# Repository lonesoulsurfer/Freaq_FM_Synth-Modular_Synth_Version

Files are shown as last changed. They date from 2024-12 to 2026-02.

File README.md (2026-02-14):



# Freaq_FM_Synth-Modular_Synth_Version

UPDATE: I have updated the original Freq Code so it now works on the current Mozzi Library.  You can find this updated code in the 'Freaq_Updated_Code' file.  I don't believe that there is any difference in sound quality and it is exactkly the same as the original which I have also included.  Both files can be found in the 'Frea_IDE_Code' folder

 The awesome Freaq FM Synth by MeeBleeps - designed for Eurorack Synths

Youtube Vid - https://www.youtube.com/watch?v=fAgmykZD0DI&source_ve_path=Mjg2NjY

First and foremost - I need to do a huge shoutout to MeeBleeps who designed this amazing synth! - https://github.com/Meebleeps/MeeBleeps-Freaq-FM-Synth

My contribution has been the design of a PCB and front panel to suit a Eurorack to suit modular synth builds.  It can be run from 12V power supply via a power connector used on on Euroracks or a 9V power supply via a JST connector.

It also can be used as a standalone synth and hand on heart, holds up to most mini synths you can buy.

The main goal with building this module is to create my own 'simple to build' modular synth. I wanted to keep everything as easy as possble with each module built with the following aims:

 - Can be powered by 9V (and 12V)
 - Easy to build with minimum components
 - Use Arduino to keep it simple (plus it helps to keep the components down and everything in tune)
 - Can fit into any modular synth Eurorck (include the ability to power the module via normal module power sources)
 - Has to sound great!

I've created a step by step guide on my Instructables page which you can find below.  This goes through how to upload the sketch using the correct version of Mozzie (1.1.2).  
https://www.instructables.com/Freaq-FM-Synth/

The Freaq FM Synth features dual independent 2-operator FM voices paired with a 2-track generative sequencer. You can stack the voices so they are in unison or have them in different polymeric step-counts. This allows you to have one voice play bass and the other lead.

This is one funky little machine! There are a tonne of controls and waveforms along with attack/delay envelope and LFO per voice.

Full instructions can be found in the Github repository



NOTE - the default start-up on the Freaq has mutation and density very low which means you might only hear a couple bleeps and boops and not much else.  To get the synth going just turn the mutation knob fully left then fully right.  Then hold down the FUNC button and do the same thing again.  This will reset the mutation & density and you'll be good to go.

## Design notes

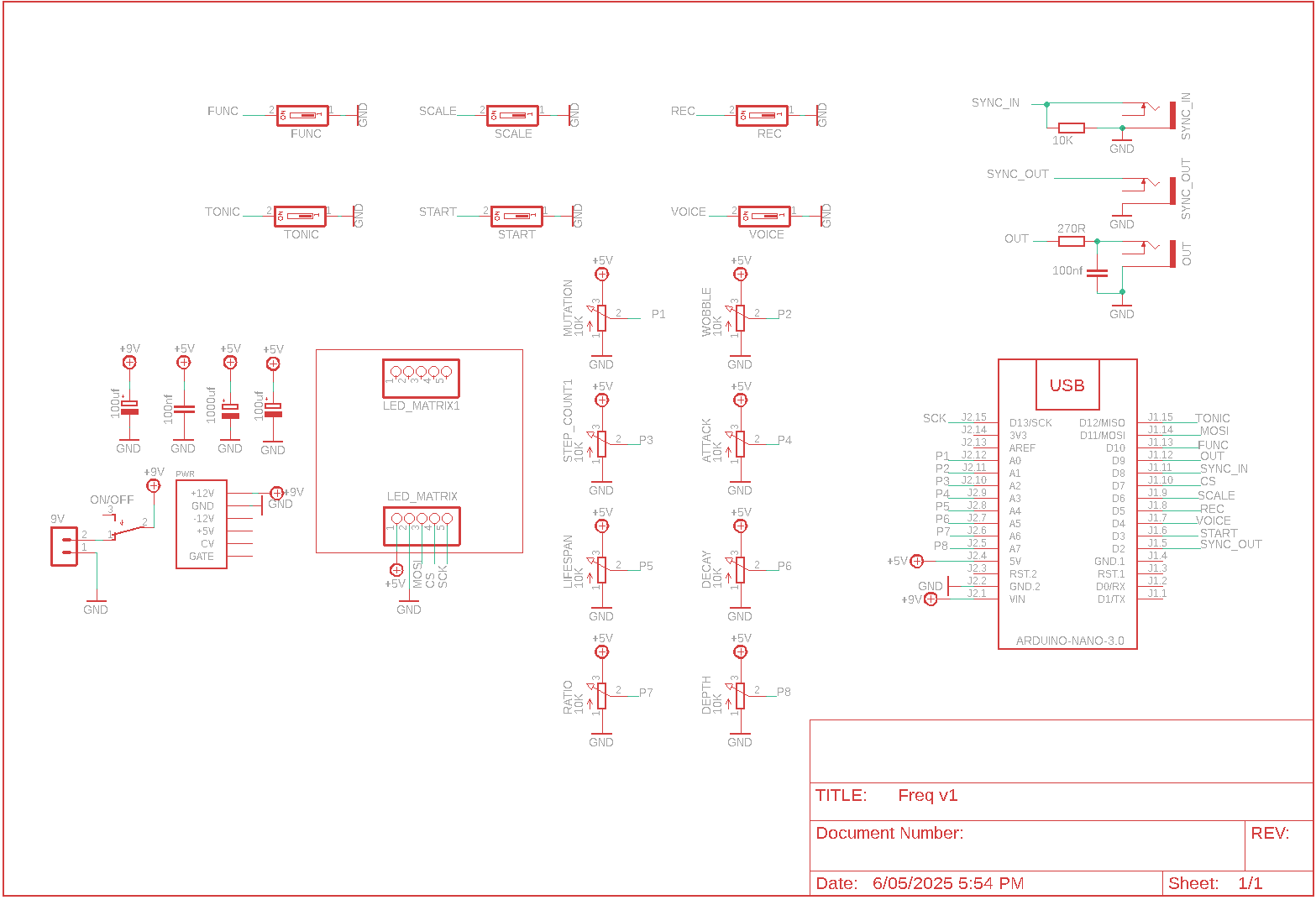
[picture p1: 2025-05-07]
Schematic.png

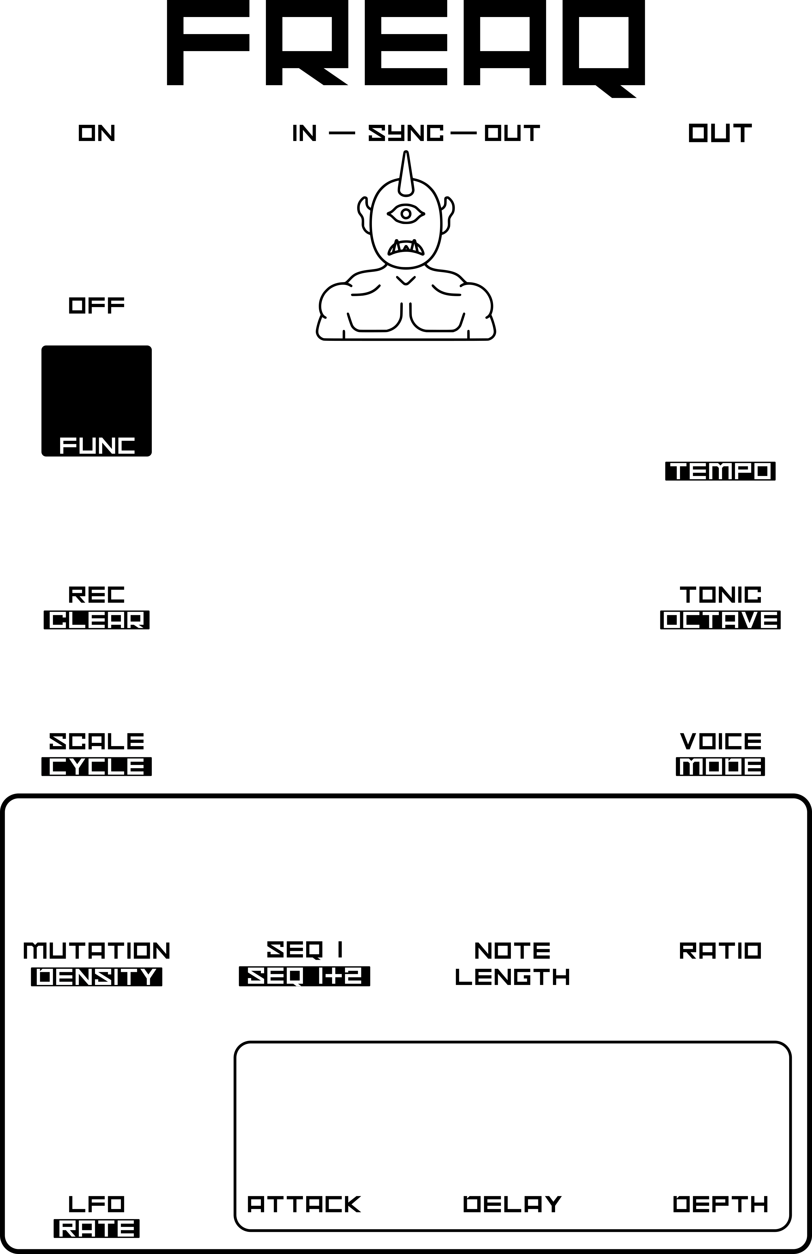
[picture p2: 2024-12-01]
Front Panel.png

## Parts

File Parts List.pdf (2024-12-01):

Part Type Value Qty | Image | Link | Notes
Capacitor Polypropylene 104J 100nf 2 | | Link (https://vi.aliexpress.com/w/wholesale-capacitor-100nf.html?spm=a2g0o.productlist.search.0)
100uf 2 Capacitor Polarized esr 1000uf 1 | | Link (https://vi.aliexpress.com/w/wholesale-capacitor-100uf-.html?spm=a2g0o.productlist.search.0) Link (https://vi.aliexpress.com/w/wholesale-capacitor-1000uf-esr.html?spm=a2g0o.productlist.search.0) | I like to use high frequency, low noise capacitors

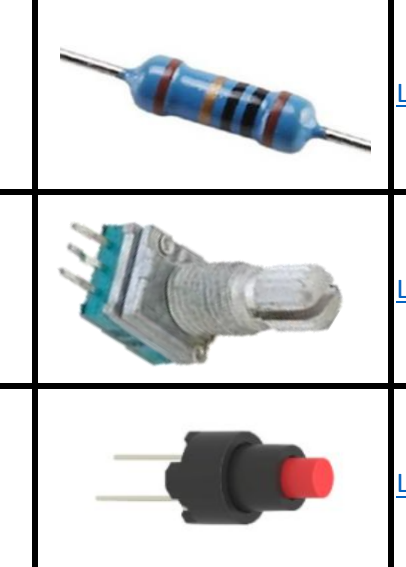
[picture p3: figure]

10K 1 Resistors Metal Film 1% 270R 1 | | Link (https://vi.aliexpress.com/w/wholesale-resistor-metal-film.html?spm=a2g0o.productlist.search.0)
Potentiometers 9mm Vertical 10K 6 | | Link (https://www.aliexpress.com/w/wholesale-9mm-vertical-potentiometer.html) | Use the metal sharft type. You can use the nut on these to help secure the front panel to the PCB
Momentary (PN SKRCADD010) 8 Switch On/Off Toggle Switch Through 1 Hole version | | Link (https://www.aliexpress.com/w/wholesale-SKRCADD010.html?spm=a2g0o.productlist.search.0) Link (https://vi.aliexpress.com/item/1005001510219617.html) | Make sure that the pins on the switch are Stich pins and are able to go through the holes in the PBC
LED Dot Matrix TZT MAX7219 1 | | Link | Here is an exact link to the one that I used (https://vi.aliexpress.com/item/1005004118366858.html)
Female Header Pin Socket 15 Pin 2 | | Link (https://vi.aliexpress.com/w/wholesale-Single-Row-Female-2.54MM-Spacing-Pin.html) | These are used to hold the Arduino into place. You could solder the Arduino onto the PCB but be careful of shorts that may happen against the components on the other side
Arduino Nano 3 1 | | Link (https://vi.aliexpress.com/w/wholesale-arduino-nano.html?spm=a2g0o.detail.search.0)

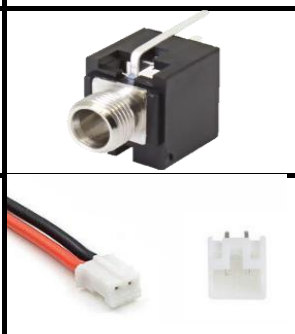
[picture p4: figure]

Audio Socket 3.5mm (PN - PJ-301M) 3 | | Link (https://vi.aliexpress.com/item/1005005352992401.html?scm_id=1007.40050.354490.0&scm-url=1007.40050.354490.0)
Mini JST Connector and wire 2 Pin 1 | | Link (https://vi.aliexpress.com/item/1005005939956886.html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) | This is used to either power the PCB or to test it. If you are going with the 9v battery then you could leave this

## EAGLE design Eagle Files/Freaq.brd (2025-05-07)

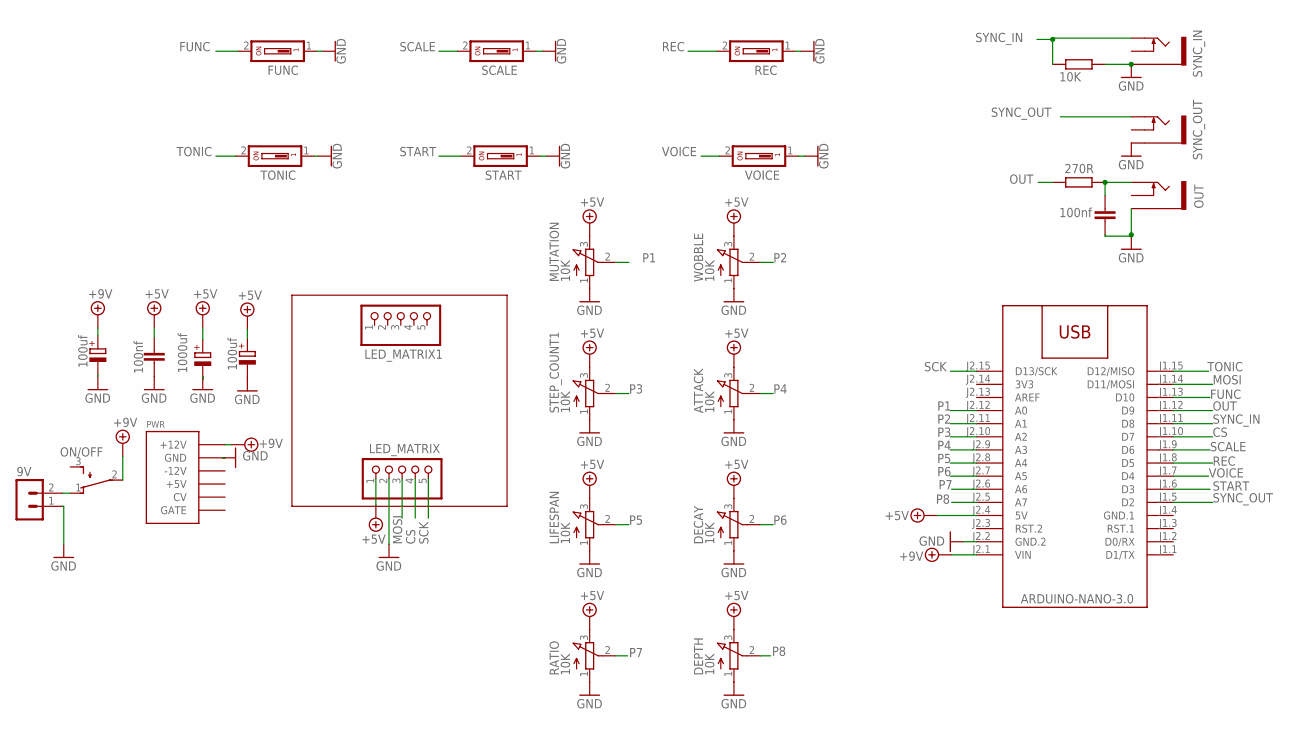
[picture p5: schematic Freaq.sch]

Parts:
9V: B2B-PH-K-S
ATTACK: 10K; EVUFXL
C1, C4: 100nf; C050-024X044
C2, C3: 100uf; E2-5
C5: 1000uf; E2,5-6E
DECAY: 10K; EVUFXL
DEPTH: 10K; EVUFXL
FUNC: DS01; DS-01
LED_MATRIX, LED_MATRIX1: PINHD-1X5; 1X05
LIFESPAN: 10K; EVUFXL
M1: ARDUINO-NANO-3.0
MUTATION: 10K; EVUFXL
ON/OFF: TL32PO; TL3XPO
OUT: THONKICONNNEW; WQP-PJ301M-12_JACK
PWR: POWER; POWER_16
R7: 10K; 0207/10
R8: 270R; 0207/10
RATIO: 10K; EVUFXL
REC: DS01; DS-01
SCALE: DS01; DS-01
START: DS01; DS-01
STEP_COUNT1: 10K; EVUFXL
SYNC_IN: THONKICONNNEW; WQP-PJ301M-12_JACK
SYNC_OUT: THONKICONNNEW; WQP-PJ301M-12_JACK
TONIC: DS01; DS-01
VOICE: DS01; DS-01
WOBBLE: 10K; EVUFXL

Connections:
3V3: M1.J2.14 (3V3)
+5V: ATTACK.3 (E), C1.1, C2.+, C5.+, DECAY.3 (E), DEPTH.3 (E), LED_MATRIX.1, LIFESPAN.3 (E), M1.J2.4 (5V), MUTATION.3 (E), RATIO.3 (E), STEP_COUNT1.3 (E), WOBBLE.3 (E)
+9V: C3.+, M1.J2.1 (VIN), ON/OFF.2, PWR.9 (+12V), PWR.10 (+12V)
CS: LED_MATRIX.4, M1.J1.10 (D7)
FUNC: FUNC.2, M1.J1.13 (D10)
GND: 9V.1, ATTACK.1 (A), C1.2, C2.-, C3.-, C4.2, C5.-, DECAY.1 (A), DEPTH.1 (A), FUNC.1, LED_MATRIX.2, LIFESPAN.1 (A), M1.J2.2 (GND.2), MUTATION.1 (A), OUT.P$3_SLEEVE (SLEEVE), PWR.3 (GND), PWR.4 (GND), PWR.5 (GND), PWR.6 (GND), PWR.7 (GND), PWR.8 (GND), R7.2, RATIO.1 (A), REC.1, SCALE.1, START.1, STEP_COUNT1.1 (A), SYNC_IN.P$3_SLEEVE (SLEEVE), SYNC_OUT.P$3_SLEEVE (SLEEVE), TONIC.1, VOICE.1, WOBBLE.1 (A)
GND.1: M1.J1.4 (GND.1)
MOSI: LED_MATRIX.3, M1.J1.14 (D11/MOSI)
unnamed: 9V.2, ON/OFF.1 (O)
unnamed: C4.1, OUT.P$1_TIP (TIP), R8.2
OUT: M1.J1.12 (D9), R8.1
P1: M1.J2.12 (A0), MUTATION.2 (S)
P2: M1.J2.11 (A1), WOBBLE.2 (S)
P3: M1.J2.10 (A2), STEP_COUNT1.2 (S)
P4: ATTACK.2 (S), M1.J2.9 (A3)
P5: LIFESPAN.2 (S), M1.J2.8 (A4)
P6: DECAY.2 (S), M1.J2.7 (A5)
P7: M1.J2.6 (A6), RATIO.2 (S)
P8: DEPTH.2 (S), M1.J2.5 (A7)
REC: M1.J1.8 (D5), REC.2
SCALE: M1.J1.9 (D6), SCALE.2
SCK: LED_MATRIX.5, M1.J2.15 (D13/SCK)
START: M1.J1.6 (D3), START.2
SYNC_IN: M1.J1.11 (D8), R7.1, SYNC_IN.P$1_TIP (TIP)
SYNC_OUT: M1.J1.5 (D2), SYNC_OUT.P$1_TIP (TIP)
TONIC: M1.J1.15 (D12/MISO), TONIC.2
VOICE: M1.J1.7 (D4), VOICE.2

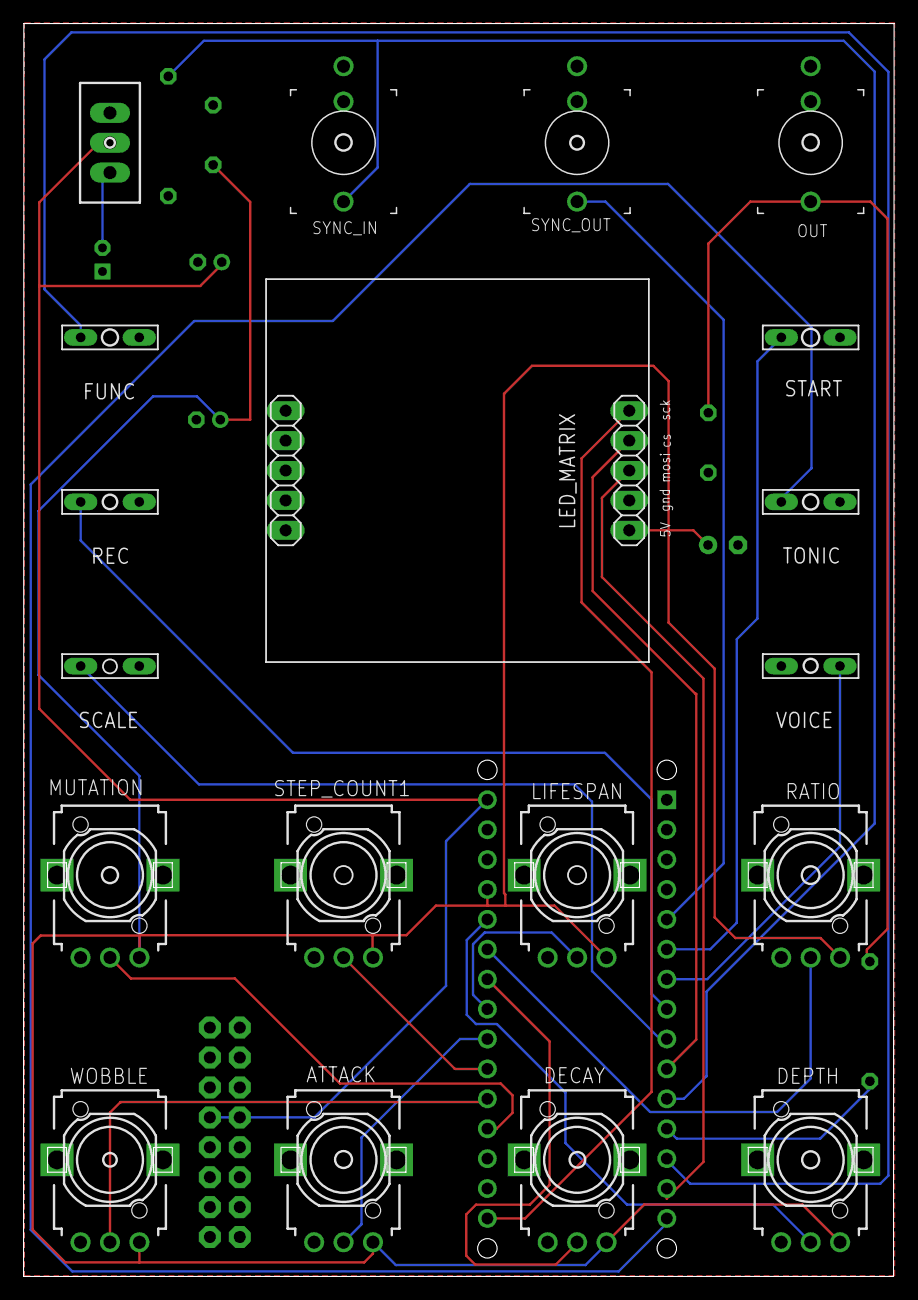
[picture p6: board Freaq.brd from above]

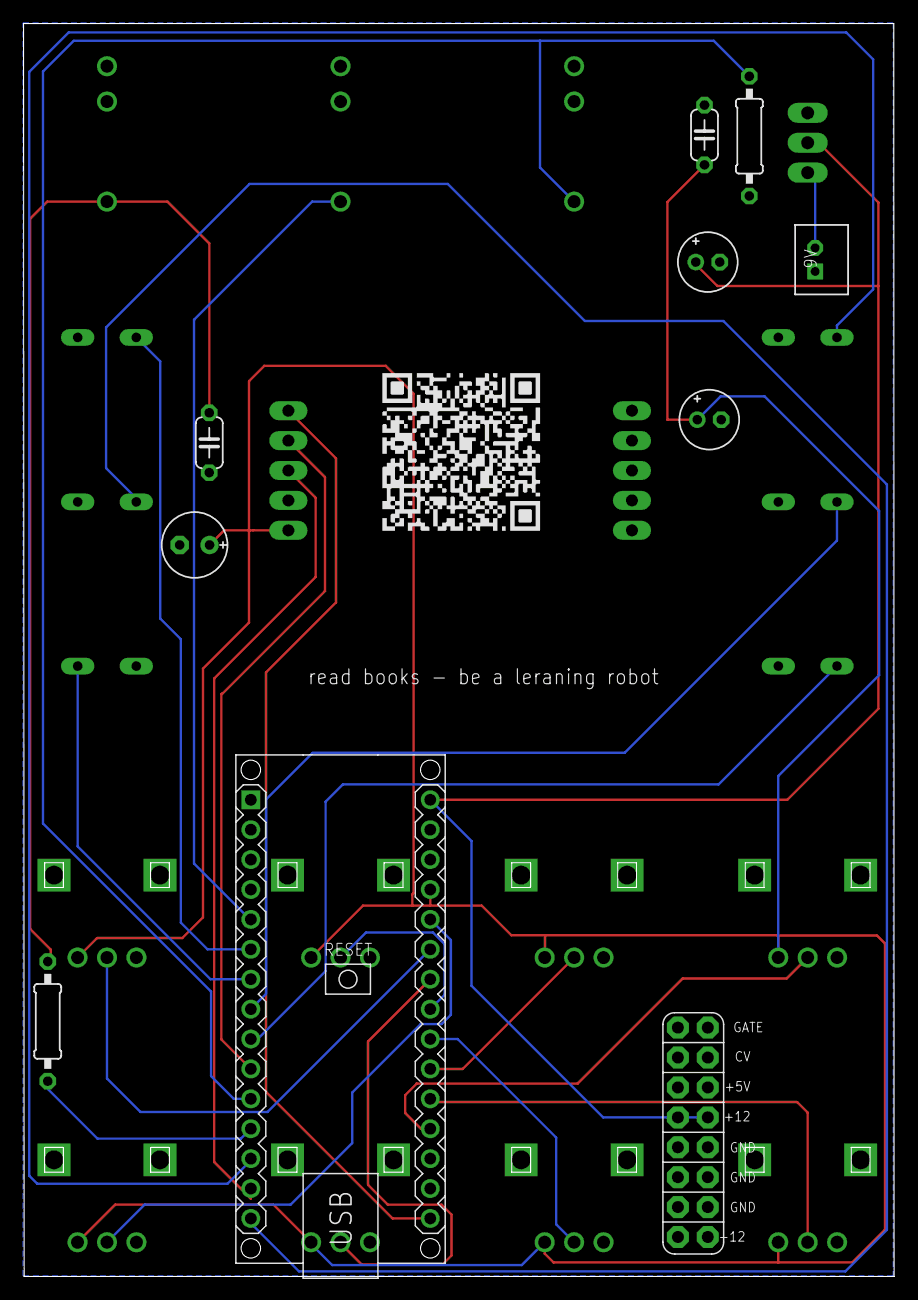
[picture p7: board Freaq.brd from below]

Board: 2 copper layers, 73.9 x 106.4 mm, 30 parts (10 on the bottom side), 25 nets.

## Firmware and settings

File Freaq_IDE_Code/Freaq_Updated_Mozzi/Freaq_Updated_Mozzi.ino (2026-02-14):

/*----------------------------------------------------------------------------------------------------------
 * MutantFMSynth.ino
 * 
 * Main project file for the Mutant FM Synth. 
 * 
 * Instantiates all mutant class objects 
 * Calls the Mozzi audio hook functions
 * manages the user interface
 * 
 * Source Code Repository:  https://github.com/Meebleeps/MeeBleeps-Freaq-FM-Synth
 * Youtube Channel:         https://www.youtube.com/channel/UC4I1ExnOpH_GjNtm7ZdWeWA
 * 
 * (C) 2021-2022 Meebleeps
*-----------------------------------------------------------------------------------------------------------
*/

#include <Arduino.h>

// Mozzi 2.0 Configuration - MUST be before including Mozzi.h
#define MOZZI_CONTROL_RATE 128
#include <Mozzi.h>

#include <mozzi_rand.h>
#include <EventDelay.h>


#include "avSource.h"
#include "avSequencerMultiTrack.h"
#include "avMidi.h"
#include "LedMatrix.h"
#include "mutantBitmaps.h"
#include <avr/pgmspace.h>

#include "MutantFMSynthOptions.h"

// define the pins
#define PIN_SYNC_IN       8
#define PIN_SYNC_OUT      2
#define TIMER_SYNC_PULSE_OUTPUT_MILLIS 15

#define PIN_AUDIO_OUT     9
#define PIN_BUTTON0       4
#define PIN_BUTTON1       5
#define PIN_BUTTON2       6
#define PIN_BUTTON3       3
#define PIN_BUTTON4       10
#define PIN_BUTTON5       12
#define MAX_BUTTON_INPUTS 6

#define SEQUENCER_TRACK_0   0
#define SEQUENCER_TRACK_1   1
#define SEQUENCER_TRACK_0_DISPLAY_ROW_0   4
#define SEQUENCER_TRACK_0_DISPLAY_ROW_1   5
#define SEQUENCER_TRACK_1_DISPLAY_ROW_0   6
#define SEQUENCER_TRACK_1_DISPLAY_ROW_1   7
#define LFO_TRACK_0_DISPLAY_ROW           2
#define LFO_TRACK_1_DISPLAY_ROW           2
#define TRIGGER_DISPLAY_ROW               0
#define TRIGGER_DISPLAY_COL               7
#define CURRENT_VOICE_DISPLAY_ROW         1

#define MAX_ANALOG_INPUTS               8
#define MAX_ANALOG_VALUE                1023

#define ANALOG_INPUT_MOD_AMOUNT         7
#define ANALOG_INPUT_DECAY              4
#define ANALOG_INPUT_MUTATION           0
#define ANALOG_INPUT_LFO                1
#define ANALOG_INPUT_MOD_RATIO          6
#define ANALOG_INPUT_STEPCOUNT          2
#define ANALOG_INPUT_MOD_ENVELOPE1      5
#define ANALOG_INPUT_MOD_ENVELOPE2      3

#define ANALOG_INPUT_MOVEMENT_THRESHOLD 5

// listed in order of left to right.
#define BUTTON_INPUT_FUNC   4
#define BUTTON_INPUT_TONIC  5
#define BUTTON_INPUT_SCALE  2
#define BUTTON_INPUT_START  3
#define BUTTON_INPUT_REC    1
#define BUTTON_INPUT_VOICE  0
#define MAX_OSCILLATOR_MODES 1

#define INTERFACE_MODE_NORMAL 0
#define INTERFACE_MODE_SHIFT  1

#define DISPLAY_SETTING_CHANGE_PERSIST_MILLIS 350
#define DISPLAY_SETTING_INTENSITY 1

#define MOTION_RECORD_NONE  0
#define MOTION_RECORD_REC   1
#define MOTION_RECORD_CLEAR 2

// MOZZI variables
// MOZZI_CONTROL_RATE now defined at top of file (before Mozzi.h include)
// original had at 256 but as CPU got tight had to reduce it
// needs to be at least 128. 64Hz means incoming sync pulses are regularly missed between updates.

// todo:  decrease INTERFACE_UPDATE_DIVIDER  if controls are externally modulated via CV voltage inputs
#define INTERFACE_UPDATE_DIVIDER_ANALOG 5
#define INTERFACE_UPDATE_DIVIDER_DIGITAL 7
#define INTERFACE_UPDATE_DIVIDER_LFO 2
#define INTERFACE_UPDATE_DIVIDER_DISPLAY 32


byte firstTimeStart = true;
byte iTrigger = 1;      
byte iLastTrigger = 0;
byte interfaceMode    = INTERFACE_MODE_NORMAL;
byte controlSynthVoice = 0;
byte motionRecordMode = MOTION_RECORD_NONE;

int iLastAnalogValue[MAX_ANALOG_INPUTS]    = {0,0,0,0,0,0,0,0};
int iCurrentAnalogValue[MAX_ANALOG_INPUTS] = {0,0,0,0,0,0,0,0};

// save space for digital inputs - use a bit rather than a byte per button 
uint8_t bitsLastButton;

// save space for digital inputs - use a bit rather than a byte per button 
uint8_t bitsCurrentButton;

// save space for param lock flags - use a bit rather than a byte per param 
uint8_t bitsLastParamLock;

// time since the last updateAudio()
uint32_t lastUpdateMicros;

// used to divide the calls to updateControl to spread out control reads and save cpu cycles 
uint8_t updateCounter = 0;




// voice 1 instance
MutatingFM          voice0;

// voice 2 instance
MutatingFM          voice1;

// array of pointers to the MutatingFM instances to simplfy the code
MutatingFM*         voices[2];  

// MAX7219 display matrix interface class
LedMatrix           ledDisplay;

// timer to pull sync output low at end of pulse
EventDelay          syncOutputTimer;

// timer to prevent update of the display while a settings icon is being displayed
EventDelay          settingDisplayTimer;

// the sequencer
MutatingSequencerMultiTrack sequencer;





/*----------------------------------------------------------------------------------------------------------
 * setup()
 *----------------------------------------------------------------------------------------------------------
 */
void setup() 
{
  #ifdef ENABLE_MIDI_OUTPUT
  Serial.begin(31250);
  #else
  Serial.begin(115200);
  Serial.print(F("\n\n\n\n\n-----------------------------------------------------------------------\n"));
  Serial.print(F("Freaq - Mozzi-based Mutating FM Synth.   Build "));
  Serial.print  (__DATE__);
  Serial.print  (F(" "));
  Serial.println  (__TIME__);
  #endif

  initialisePins();
  initialiseDisplay();
  initialiseSources();
  initialiseSequencer();
  
  startMozzi(); // Mozzi 2.0: no parameters
}


/*----------------------------------------------------------------------------------------------------------
 * debugPrintMemoryUsage
 * does nothing now.  used while optimising memory usage 
 *----------------------------------------------------------------------------------------------------------
 */
void debugPrintMemoryUsage()
{
/*
  debugWriteValue("sizeof(synthVoice)", sizeof(synthVoice));
  debugWriteValue("sizeof(sequencer)", sizeof(sequencer));
*/  

}


/*----------------------------------------------------------------------------------------------------------
 * initialiseDisplay
 *----------------------------------------------------------------------------------------------------------
 */
void initialiseDisplay()
{
  ledDisplay.initialise();
  ledDisplay.setOrientation(LEDMATRIX_ORIENTATION_0);
  
  settingDisplayTimer.start(0);

  
  // display logo
  for (uint8_t i = 10; i < 100; i += 10)
  {
    ledDisplay.clearScreen();
    delay(i);
    displaySettingIcon(BITMAP_MEEBLEEPS);
    delay(i);
  }
  
  //fade logo to target intensity
  for(int i = 15; i>= DISPLAY_SETTING_INTENSITY; i--)
  {
    ledDisplay.setIntensity(i);

    delay(20);
  }
  
//  ledDisplay.setIntensity(DISPLAY_SETTING_INTENSITY);
//  displaySettingIcon(BITMAP_MEEBLEEPS);

  #ifndef ENABLE_MIDI_OUTPUT
  Serial.println(F("initialiseDisplay() complete"));
  #endif
}




/*----------------------------------------------------------------------------------------------------------
 * initialisePins
 *----------------------------------------------------------------------------------------------------------
 */
void initialisePins()
{
  #ifndef ENABLE_MIDI_OUTPUT
  Serial.println(F("initialisePins()"));
  #endif

  pinMode(PIN_SYNC_IN, INPUT);          // sync is pulled down by external pulldown resistor
  pinMode(PIN_SYNC_OUT, OUTPUT);
  pinMode(PIN_BUTTON0, INPUT_PULLUP);   // all other buttons are pulled up by internal pullup resistor
  pinMode(PIN_BUTTON1, INPUT_PULLUP);
  pinMode(PIN_BUTTON2, INPUT_PULLUP);
  pinMode(PIN_BUTTON3, INPUT_PULLUP);
  pinMode(PIN_BUTTON4, INPUT_PULLUP);
  pinMode(PIN_BUTTON5, INPUT_PULLUP);

  pinMode(A0, INPUT);
  pinMode(A1, INPUT);
  pinMode(A2, INPUT);
  pinMode(A3, INPUT);
  pinMode(A4, INPUT);
  pinMode(A5, INPUT); 
  pinMode(A6, INPUT);
  pinMode(A7, INPUT); 

  // initialise 
  bitsLastButton    = 0;
  bitsCurrentButton = 0;

  for (uint8_t i = 0; i < MAX_ANALOG_INPUTS; i++)
  {
    iLastAnalogValue[i]    = 0;
  }
}



/*----------------------------------------------------------------------------------------------------------
 * initialiseSources
 *----------------------------------------------------------------------------------------------------------
 */
void initialiseSources()
{
  voice0.setOscillator(0);
  voice1.setOscillator(1);

  voices[0] = &voice0;  
  voices[1] = &voice1;  
}



/*----------------------------------------------------------------------------------------------------------
 * initialiseSequencer
 *----------------------------------------------------------------------------------------------------------
 */
void initialiseSequencer()
{
  sequencer.setScale(SCALEMODE_MINOR);
  sequencer.newSequence(16);
  sequencer.setMutationProbability(100);  // Mutation fully on (100%)
  sequencer.setNoteProbability(100);      // Density fully on (100%)
}




/*----------------------------------------------------------------------------------------------------------
 * updateControl
 * called by Mozzi Library on CONTROL_RATE frequency
 * spreads out control logic updates so that we don't bog down the CPU
 *
 * every step - check for sync trigger and update sequencer
 * if this gets delayed, note on/off commands will drift
 *----------------------------------------------------------------------------------------------------------
 */
void updateControl()
{
  uint8_t doDisplayUpdate = false;

  lastUpdateMicros = micros();
  updateCounter++;



  // check for incoming sync trigger and if necessary update output sync
  // do every update to ensure minimum sync jitter 
  updateSyncTrigger();

  // update sequencer returns true if the sequencer has moved to next step
  if (updateSequencer())
  {

    // check to see if sequencer should update the output sync pulse
    if (sequencer.outputSyncPulse())
    {
      outputSyncPulse();
    }

    //update the display once per sequencer step   
    // but do the display update at the end of updateControl so that any latency is introduced after all critical functions are processed

    doDisplayUpdate = true; 
  }
  // check controls once every INTERFACE_UPDATE_DIVIDER steps for efficiency
  // don't update these if the sequencer has updated as that is expensive
  else if(updateCounter % INTERFACE_UPDATE_DIVIDER_ANALOG == 0)
  {
    // now check analog controls
    updateAnalogControls();
  
  }
  // never check both analog and digital controls in the same step to causing buffer underflows
  else if(updateCounter % INTERFACE_UPDATE_DIVIDER_DIGITAL == 0)
  {
    // check button controls first to ensure interface mode is correctly set
    updateButtonControls();

  }
  else if(updateCounter % INTERFACE_UPDATE_DIVIDER_LFO == 0)
  {
    //update display of LFO modulation at higher rate than rest of display
    updateLFOModulationDisplay();
  }
  else 
  {
    doDisplayUpdate = (updateCounter % INTERFACE_UPDATE_DIVIDER_DISPLAY == 0);
  }

  #ifndef ENABLE_MIDI_OUTPUT
  //Serial.print(micros() - lastUpdateMicros);
  //Serial.print(F(","));
  #endif

  // now that all controls are updated, update the source.

  voices[0]->updateControl();
  voices[1]->updateControl();

  #ifndef ENABLE_MIDI_OUTPUT
  /*
  Serial.print(micros() - lastUpdateMicros);
  Serial.print(F(","));
  Serial.print(updateCounter % INTERFACE_UPDATE_DIVIDER_DIGITAL);
  Serial.print(F(","));
  Serial.print(updateCounter % INTERFACE_UPDATE_DIVIDER_ANALOG);
  Serial.print(F(","));
  Serial.print(sequenceUpdated);
  Serial.println();
  */
  #endif

  // do the display update last so that any latency is introduced after the notes are updated
  if (doDisplayUpdate)
  {
    updateDisplay();
  }

}



/*----------------------------------------------------------------------------------------------------------
 * updateLFOModulationDisplay
 * displays the current position of the 2 LFOs using 4 LEDs each
 *----------------------------------------------------------------------------------------------------------
 */
void updateLFOModulationDisplay()
{
  if (!firstTimeStart && settingDisplayTimer.ready())
  {
    // divide LFO value of 0-255 to range 0-3 by right-shift 6 bits, then right-shift 128 by that value to get the correct pixel bitfield
    // originally used floating point maths - very slow.
    ledDisplay.setRowPixels(LFO_TRACK_0_DISPLAY_ROW, (128 >> (voice0.getLFOValue() >> 6)) | (8 >> (voice1.getLFOValue() >> 6)));
    
    ledDisplay.refresh();
  }
}



/*----------------------------------------------------------------------------------------------------------
 * updateSequencer
 * updates sequencer
 * returns true if the sequencer advances a step
 *----------------------------------------------------------------------------------------------------------
 */
int updateSequencer()
{
  byte nextNote[MAX_SEQUENCER_TRACKS];
  uint16_t nextNoteLength;
  
  // if the sequencer is due to make a new step, 
  if (sequencer.update(false))
  {
    nextNoteLength  = sequencer.getNextNoteLength();

    for (uint8_t i=0; i<MAX_SEQUENCER_TRACKS; i++) 
    {
      nextNote[i] = sequencer.getCurrentNote(i);
     
      if (nextNote[i] > 0)
      {
        //todo: find way to extend param locks to channel 2?
        if (i==0)
        {
          getParameterLocks();
        }

        voices[i]->noteOn(nextNote[i], 255, nextNoteLength);

      }
    }
    #ifdef ENABLE_MIDI_OUTPUT
    //midiNoteOn(1,nextNote[0],127);
    if (nextNote[0])
    {
      Serial.write(0x90);
      Serial.write(nextNote[0]-24);
      Serial.write(0x45);
    }
    #else

    #endif


    return true;
  }
  else
  {
    return false;
  }

  
}



/*----------------------------------------------------------------------------------------------------------
 * outputSyncPulse
 * sends a digital signal to the output pin and sets the timer to pull it low after TIMER_SYNC_PULSE_OUTPUT_MILLIS
 *----------------------------------------------------------------------------------------------------------
 */
void outputSyncPulse()
{
  /*
  DEBUG only
  static uint32_t lastSyncOutTimeMicros;
  static uint32_t thisSyncOutTimeMicros;

  thisSyncOutTimeMicros = mozziMicros();
  Serial.print(F("lastSyncOutTimeMicros = "));
  Serial.println(thisSyncOutTimeMicros - lastSyncOutTimeMicros);
  lastSyncOutTimeMicros = thisSyncOutTimeMicros;
  */

  syncOutputTimer.start(TIMER_SYNC_PULSE_OUTPUT_MILLIS);
  digitalWrite(PIN_SYNC_OUT,  HIGH);
}


/*----------------------------------------------------------------------------------------------------------
 * getParameterLocks
 * updates source parameters based on stored modulation sequence
 * parameter locks are only available for first track only.
 *----------------------------------------------------------------------------------------------------------
 */
void getParameterLocks()
{
  uint16_t  thisParamLock;
  uint8_t   thisStep;
  int8_t    synthParamIndex;

  // parameters are recorded on the longest sequence but only applied to track 1 voice
  // this way if track 1 is 5 steps but track 2 is 16 steps, the automation will be 16 steps long
  if (sequencer.getSequenceLength(SEQUENCER_TRACK_1) > sequencer.getSequenceLength(SEQUENCER_TRACK_0))
  {
    thisStep = sequencer.getCurrentStep(SEQUENCER_TRACK_1);
  }
  else
  {
    thisStep = sequencer.getCurrentStep(SEQUENCER_TRACK_0);
  }

  for (uint8_t paramIndex = 0; paramIndex < MAX_PARAMETER_LOCKS; paramIndex++)
  {
    thisParamLock = sequencer.getParameterLock(paramIndex, SEQUENCER_TRACK_0, thisStep);
    
    if (thisParamLock != 0)
    {
      #ifndef ENABLE_MIDI_OUTPUT

      /*
      Serial.print(F("parameter lock for channel "));
      Serial.print(SEQUENCER_TRACK_0);
      Serial.print(F(" parameter "));
      Serial.print(paramIndex);
      Serial.print(F(" value "));
      Serial.println(thisParamLock);
      */
      #endif

      // set the flag for this input - last parameter was a lock
      bitsLastParamLock |= 1 << paramIndex;
    }
    else 
    {
      // if the last step was a parameter lock but this step doesn't have one, set the parameter lock to the current knob position
      if ((bitsLastParamLock >> paramIndex) & 1)
      {
        #ifndef ENABLE_MIDI_OUTPUT

        /*
        Serial.print(F("clearing last parameter lock for channel "));
        Serial.print(SEQUENCER_TRACK_0);
        Serial.print(F(" parameter "));
        Serial.print(paramIndex);
        Serial.print(F(" knob value "));
        Serial.println(iCurrentAnalogValue[getParameterLockControl(paramIndex)]);
        */
        #endif
        thisParamLock = iCurrentAnalogValue[getParameterLockControl(paramIndex)];
      }

      // reset the lock bitflag for this parameter
      bitsLastParamLock &= ~(1 << paramIndex);  

    }
    
    // if there is a parameter lock or we are recovering from a previous step parameter lock 
    if (thisParamLock != 0)
    {
      synthParamIndex = getParameterLockSynthParam(paramIndex);
      
      if (synthParamIndex == -2)
      {
        sequencer.setNextNoteLength(thisParamLock);
      }
      else if (synthParamIndex >= 0)
      {
        voices[SEQUENCER_TRACK_0]->setParam(synthParamIndex, thisParamLock);
      }
    }
    //}
  }

}



/*----------------------------------------------------------------------------------------------------------
 * setParameterLock
 * saves the given parameter value onto a modulation channel
 *----------------------------------------------------------------------------------------------------------
 */
inline void setParameterLock(int8_t paramChannel, uint16_t value)
{
  switch (motionRecordMode)
  {
    // 14/02/22: moved this here as is the most common case, assuming no branch prediction on arduion platforms
    case MOTION_RECORD_NONE:
        // do nothing 
        break;

    case MOTION_RECORD_REC:
        sequencer.setParameterLock(paramChannel, value);
        #ifndef ENABLE_MIDI_OUTPUT
        //Serial.println(F("setParameterLock(0)"));
        #endif
        break;

    case MOTION_RECORD_CLEAR:
        sequencer.clearAllParameterLocks(paramChannel);
        #ifndef ENABLE_MIDI_OUTPUT
        //Serial.println(F("Clear ParameterLock(0)"));
        #endif
        break;

  }
}



/*----------------------------------------------------------------------------------------------------------
 * getParameterLockChannel
 * returns the sequencer modulation channel for a given analog control index 
 * 
 * These are a bit of a kludge - would be better as a lookup table.
 *----------------------------------------------------------------------------------------------------------
 */
inline int8_t getParameterLockChannel(uint8_t analogControlIndex)
{
  switch(analogControlIndex)
  {
    case ANALOG_INPUT_MOD_AMOUNT:    return PARAM_LOCK_CHANNEL_0;       
    case ANALOG_INPUT_DECAY:         return PARAM_LOCK_CHANNEL_1;
    case ANALOG_INPUT_MOD_RATIO:     return PARAM_LOCK_CHANNEL_2;
    case ANALOG_INPUT_MOD_ENVELOPE1: return PARAM_LOCK_CHANNEL_3;
    case ANALOG_INPUT_MOD_ENVELOPE2: return PARAM_LOCK_CHANNEL_4;
    case ANALOG_INPUT_LFO:           return PARAM_LOCK_CHANNEL_5;
    default:  return -1;
  }
}


/*----------------------------------------------------------------------------------------------------------
 * getParameterLockControl
 * returns the analog control index for a given sequencer modulation channel 
 *----------------------------------------------------------------------------------------------------------
 */
inline int8_t getParameterLockControl(uint8_t paramChannelIndex)
{
  switch(paramChannelIndex)
  {
    case PARAM_LOCK_CHANNEL_0: return ANALOG_INPUT_MOD_AMOUNT;
    case PARAM_LOCK_CHANNEL_1: return ANALOG_INPUT_DECAY;
    case PARAM_LOCK_CHANNEL_2: return ANALOG_INPUT_MOD_RATIO;
    case PARAM_LOCK_CHANNEL_3: return ANALOG_INPUT_MOD_ENVELOPE1;
    case PARAM_LOCK_CHANNEL_4: return ANALOG_INPUT_MOD_ENVELOPE2;
    case PARAM_LOCK_CHANNEL_5: return ANALOG_INPUT_LFO;
    default:  return -1;
  }
}


/*----------------------------------------------------------------------------------------------------------
 * getParameterLockSynthParam
 * returns the sytnh parameter for a given sequencer modulation channel 
 *----------------------------------------------------------------------------------------------------------
 */
inline int8_t getParameterLockSynthParam(uint8_t paramChannelIndex)
{
  switch(paramChannelIndex)
  {
    case PARAM_LOCK_CHANNEL_0: return SYNTH_PARAMETER_MOD_AMOUNT;
    case PARAM_LOCK_CHANNEL_1: return SYNTH_PARAMETER_NOTE_DECAY;
    case PARAM_LOCK_CHANNEL_2: return SYNTH_PARAMETER_MOD_RATIO;
    case PARAM_LOCK_CHANNEL_3: return SYNTH_PARAMETER_ENVELOPE_DECAY;
    case PARAM_LOCK_CHANNEL_4: return SYNTH_PARAMETER_ENVELOPE_ATTACK;
    case PARAM_LOCK_CHANNEL_5: return SYNTH_PARAMETER_MOD_AMOUNT_LFODEPTH;
    default:  return SYNTH_PARAMETER_UNKNOWN;
  }
}






/*----------------------------------------------------------------------------------------------------------
 * updateSyncTrigger
 * check for incoming sync trigger and update sequencer
 * also check to see if output sync trigger needs to be pulled low
 *----------------------------------------------------------------------------------------------------------
 */
void updateSyncTrigger()
{
  iTrigger = digitalRead(PIN_SYNC_IN);   // read the sync pin
  if (iTrigger != iLastTrigger)
  {
    digitalWrite(PIN_SYNC_OUT, iTrigger);
    
    //trigger note on or off
    if (iTrigger == HIGH)
    {
      #ifndef ENABLE_MIDI_OUTPUT
      //Serial.println("sync!");
      #endif
      sequencer.syncPulse(SYNC_STEPS_PER_PULSE);
    }

    iLastTrigger = iTrigger;
  }

  // check to see if the output sync pulse needs to be pulled low
  if (syncOutputTimer.ready())
  {
    digitalWrite(PIN_SYNC_OUT, LOW);
  }
  
}
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
void loop() 
{
  //required for Mozzi
  audioHook();
}

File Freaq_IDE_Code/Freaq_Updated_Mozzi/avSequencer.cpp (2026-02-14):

/*----------------------------------------------------------------------------------------------------------
 * avSequencer.cpp
 * 
 * Implements a generative sequencer with multiple generative algorithms, musical scale quantisation,
 * variable sequence length (up to 16 steps) and multiple parameter-lock (motion-sequencing) channels
 * 
 * (C) 2021-2022 Meebleeps
*-----------------------------------------------------------------------------------------------------------
*/
#include "Arduino.h"
#include "avSequencer.h"

#include <MozziHeadersOnly.h>
#include <mozzi_rand.h>


/*----------------------------------------------------------------------------------------------------------
 * MutatingSequencer::MutatingSequencer()
 * initialises the sequencer
 *----------------------------------------------------------------------------------------------------------
 */
MutatingSequencer::MutatingSequencer()
{
  running             = false;
  mutationAlgorithm   = MUTATE_ALGO_DEFAULT;

  // initialise sequence
  for (uint8_t i = 0; i < MAX_SEQUENCE_LENGTH; i++)
  {
    notes[i] = 0;
  }
  
  for (uint8_t i = 0; i < MAX_SCALE_LENGTH; i++)
  {
    scaleNotes[i] = 0;
  }

  for (uint8_t i = 0; i < MAX_SEQUENCE_LENGTH; i++)
  {
    for (uint8_t m = 0; m < MAX_PARAMETER_LOCKS; m++)
    {
      parameterLocks[m][i] = 0;
    }
  }

  currentStep         = 0;  
  retrigStep          = 0;     
  retrigState         = false;                        
  tonicNote           = 9;   // default to A
  octave              = 1;                           
  mutationProbability = 0;
  noteProbability      = 70;
  tonicProbability    = 30;
  sequenceLength      = 16;
  bpm                 = 130;
  currentNote         = tonicNote;
  nextStepNoteLength  = 80;
  octaveSpread        = 3;  
  scaleNoteCount      = 7;

  // deleted this to allow for different pulse steps defined by the UI layer
  //syncPulseSteps        = 2;      // standard 2 steps per sync pulse as per volca
  syncPulseClockDivide  = 1;      // divide the clock by this many steps
  
  nextStepTimeMillis  = (15000 / bpm); // 16th note length for given BPM
  
  lastSyncPulseTimeMicros = 0;
  
  initialiseScale(SCALEMODE_PENTA);
  newSequence(sequenceLength);

  _debugOutput        = true;
  printParameters();
}



/*----------------------------------------------------------------------------------------------------------
 * MutatingSequencer::start()
 * starts the sequencer at step 0
 *----------------------------------------------------------------------------------------------------------
 */
void MutatingSequencer::start()
{
  #ifndef ENABLE_MIDI_OUTPUT
  Serial.println(F("Sequencer.Start()"));
  #endif
  running             = true;
  ignoreNextSyncPulse = true;
  //nextStep(true);
}




/*----------------------------------------------------------------------------------------------------------
 * MutatingSequencer::stop()
 * stops the sequencer
 *----------------------------------------------------------------------------------------------------------
 */
void MutatingSequencer::stop()
{
  #ifndef ENABLE_MIDI_OUTPUT
  Serial.println(F("Sequencer.Stop()"));
  #endif
  running = false;
}


/*----------------------------------------------------------------------------------------------------------
 * MutatingSequencer::toggleStart()
 * starts the sequencer if it is stopped, otherwise stops it
 *----------------------------------------------------------------------------------------------------------
 */
void MutatingSequencer::toggleStart()
{
  if (!running)
  {
    start();
  }
  else
  {
    stop();  
  }
}



/*----------------------------------------------------------------------------------------------------------
 * MutatingSequencer::setScale()
 * sets the scale and generates a new sequence according to the new scale
 *----------------------------------------------------------------------------------------------------------
 */
 void MutatingSequencer::setScale(uint8_t scaleMode)
{
  initialiseScale(scaleMode);
  newSequence(sequenceLength);
  #ifndef ENABLE_MIDI_OUTPUT
  Serial.print(F("NEW SCALE: "));
  Serial.println(scaleMode);
  #endif
}


/*----------------------------------------------------------------------------------------------------------
 * MutatingSequencer::getScale()
 * returns the current scale mode
 *----------------------------------------------------------------------------------------------------------
 */
 uint8_t MutatingSequencer::getScale()
{
  return currentScaleMode;
}


/*----------------------------------------------------------------------------------------------------------
 * MutatingSequencer::getAlgorithm()
 * returns the current mutation algorithm
 *----------------------------------------------------------------------------------------------------------
 */
uint8_t MutatingSequencer::getAlgorithm()
{
  return mutationAlgorithm;
}


/*----------------------------------------------------------------------------------------------------------
 * MutatingSequencer::setAlgorithm()
 * sets the current mutation algorithm
 *----------------------------------------------------------------------------------------------------------
 */
void MutatingSequencer::setAlgorithm(uint8_t newValue)
{
  mutationAlgorithm = newValue % MAX_MUTATE_ALGO_COUNT;
}

/*----------------------------------------------------------------------------------------------------------
 * MutatingSequencer::incrAlgorithm()
 * moves to the next algorithm
 *----------------------------------------------------------------------------------------------------------
 */
void MutatingSequencer::nextAlgorithm()
{
  mutationAlgorithm = (mutationAlgorithm + 1) % MAX_MUTATE_ALGO_COUNT;
  #ifndef ENABLE_MIDI_OUTPUT
  Serial.print(F("New Algorithm = "));
  Serial.println(mutationAlgorithm);
  #endif
}




/*----------------------------------------------------------------------------------------------------------
 * MutatingSequencer::getCurrentNote()
 * gets the note value for the current step
 *----------------------------------------------------------------------------------------------------------
 */
byte MutatingSequencer::getCurrentNote()
{
  if (!retrigState)
  {
    return notes[currentStep];
  }
  else
  {
    return notes[retrigStep];
  }
}


/*----------------------------------------------------------------------------------------------------------
 * MutatingSequencer::getCurrentStep()
 * gets  the current playing step
 *----------------------------------------------------------------------------------------------------------
 */
byte MutatingSequencer::getCurrentStep()
{
  if(!retrigState)
  {
    return currentStep;
  }
  else
  {
    return retrigStep;
  }
  
}
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

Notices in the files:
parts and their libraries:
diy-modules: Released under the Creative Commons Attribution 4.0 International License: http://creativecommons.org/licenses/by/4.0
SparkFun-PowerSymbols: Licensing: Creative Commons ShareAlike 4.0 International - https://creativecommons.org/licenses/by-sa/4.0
